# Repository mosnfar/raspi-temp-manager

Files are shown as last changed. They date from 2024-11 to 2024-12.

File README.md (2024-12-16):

# RasPi Temp Manager

A comparative tool and hardware setup for Raspberry Pi (RasPi) to manage temperature and monitor essential information.

This repository outlines a project designed to enhance the thermal management and monitoring capabilities of a Raspberry Pi 4 housed in an Argon NEO case. The project combines hardware modifications and custom software to provide effective cooling and real-time system monitoring through a small OLED display.

> [!NOTE]
> You can read the complete instructions on [The Forge blog](https://forge.mosn.me/keeping-your-raspberry-pi-cool-a-temperature-manager-tool).

<table style="width: 100%;">
  <tr>
    <th style="text-align: left;"> Final Product </th>
    <th style="text-align: left;"> Demo Video </th>
  </tr>
  <tr>
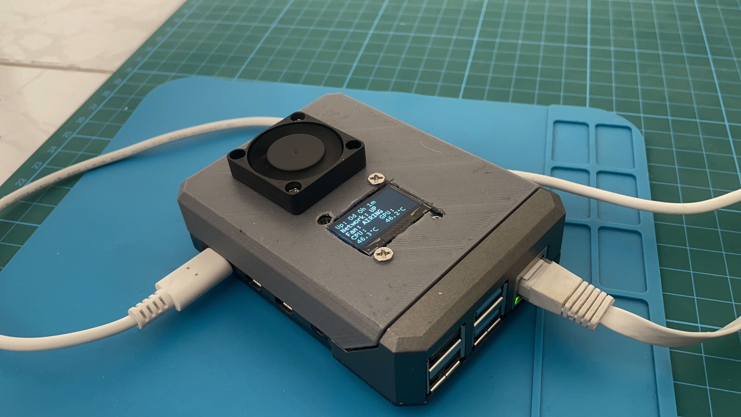
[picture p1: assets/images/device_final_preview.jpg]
Image of final product
    <td width="50%"></td>
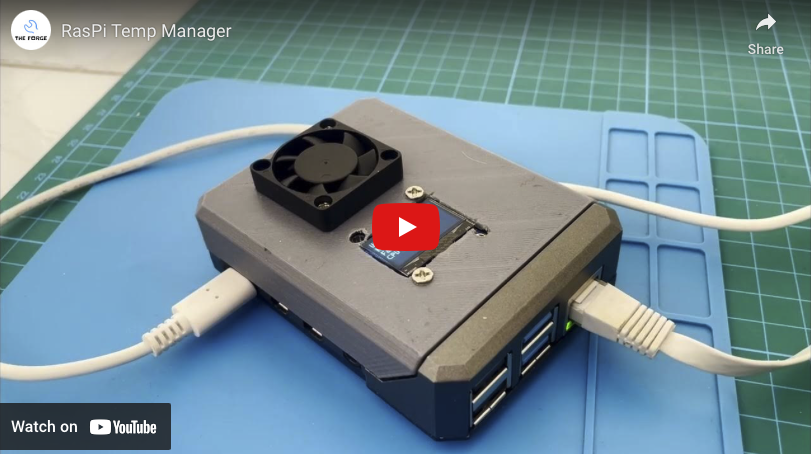
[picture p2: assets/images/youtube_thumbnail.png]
Yotube thumbnail of demo video
    <td width="50%"></td>
  </tr>
</table>

---

Table of contents:

<!-- TOC depthfrom:2 depthto:3 -->

- [:sparkles: Features](#sparkles-features)
- [:nut_and_bolt: Hardware](#nut_and_bolt-hardware)
    - [Hardware Components](#hardware-components)
    - [Schematic](#schematic)
- [:package: 3D Case](#package-3d-case)
- [:computer: Software](#computer-software)
- [:information_desk_person: More Information](#information_desk_person-more-information)
    - [Image Gallery](#image-gallery)
    - [Complete Instruction](#complete-instruction)
    - [Contribution](#contribution)

<!-- /TOC -->

---

## :sparkles: Features
- **Dynamic Cooling**: Automatically adjusts the fan speed according to system temperature thresholds.
- **Real-Time Monitoring**: Displays key metrics like:
  - CPU & GPU temperature
  - Network status
  - System overview
- **Compact Design**: Retains the Argon NEO case's form factor with minimal modifications.

## :nut_and_bolt: Hardware

### Hardware Components

1. **128×64 px OLED Display (SSD1306):** Uses I2C protocol to display system metrics, including temperature, system, and network status.
2. **Miniature 5V Fan:** Provides active cooling to maintain optimal system temperature.
3. **DRV8833 Dual Motor Driver:** Controls the 5V fan with PWM for precise speed adjustments.
4. **Raspberry Pi 4:** Serves as the mainboard.

### Schematic

Here is the schematic for connecting all components to the Raspberry Pi GPIO.

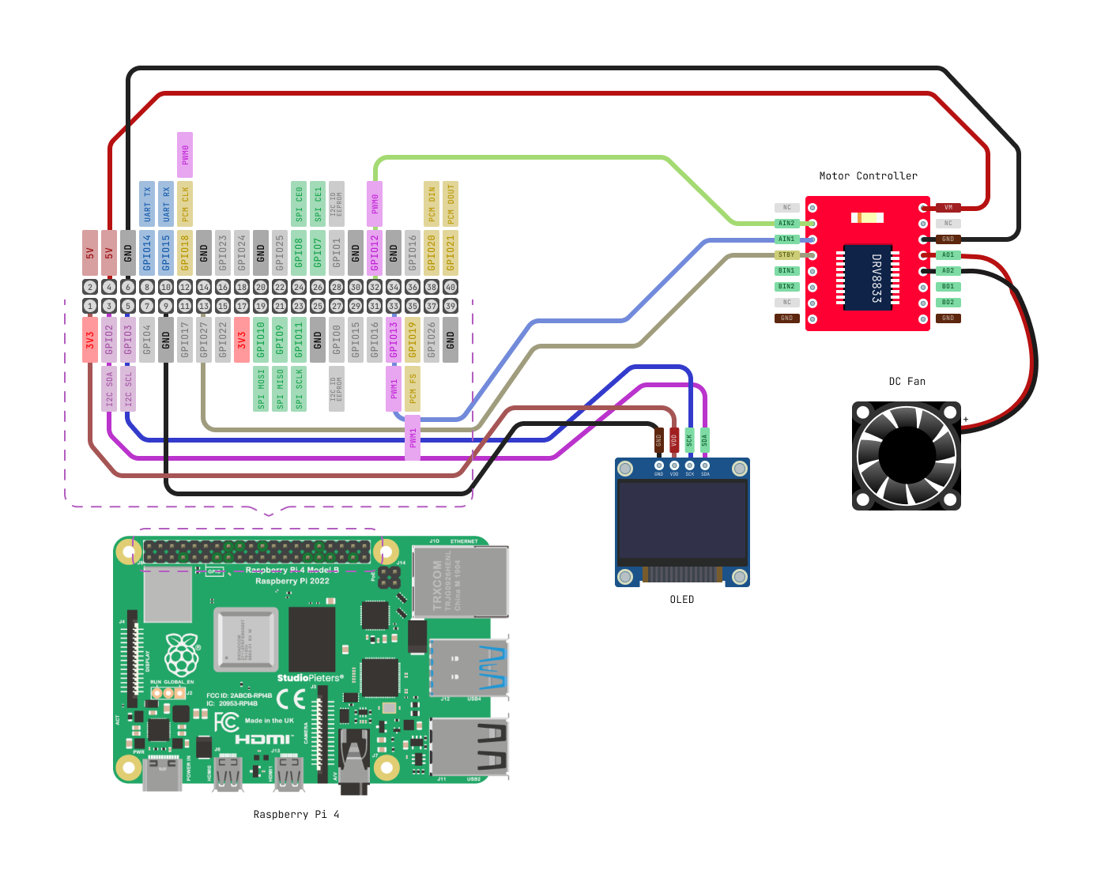
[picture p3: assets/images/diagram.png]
Schematic Diagram


#### DRV8833 Driver ←→ Rasberry Pi
| *DRV8833* | *Raspberry Pi 4 GPIO* |
| --- | --- |
| AIN1 | GPIO13 |
| AIN2 | GPIO12 |
| VM | 5V (Pin #4) |
| GND | GND (Pin #6) |
| STBY | GPIO27 |

#### 5V Fan ←→ DRV8833 Driver
| *5V Fan* | *DRV8833 Driver* |
| --- | --- |
| 5V (RED) | AIO1 |
| GND (BLACK) | AIO2 |

#### OLED (SSD1306) ←→ Raspberry Pi
| *OLED - SSD1306* | *Raspberry Pi 4 GPIO* |
| --- | --- |
| VCC | 3v3 (Pin #1) |
| SDA | GPIO2 |
| SCL | GPIO3 |
| GND | GND (Pin #9) |

## :package: 3D Case

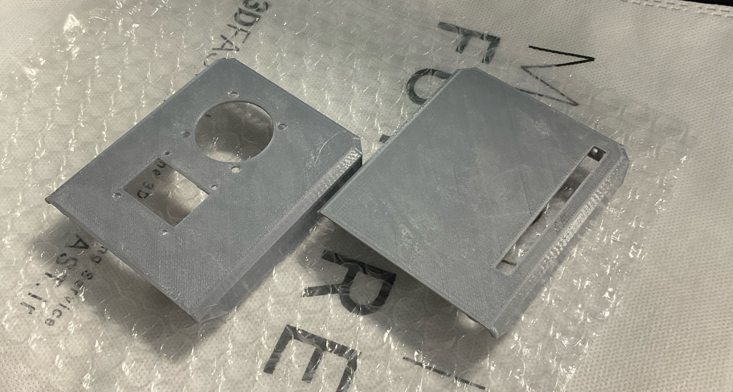
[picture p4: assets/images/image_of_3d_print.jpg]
Image of 3D printed part


I used the [Argon NEO Case](https://argon40.com/products/argon-neo-case-for-raspberry-pi-4) for my raspberry pi 4 and I modified this case to place the components. You can find the 3D design file in the [`./3d-files` directory](/3d-files/) or through this [link](https://www.printables.com/model/1085113-rascase-raspberry-pi-argon-neo-case-add-on). You can also 3D print any other case of your choice to house the components. 

## :computer: Software

#### 01. Clone Repository

Clone the repository into your raspberry pi:

```bash
git clone https://github.com/mosnfar/raspi-temp-manager
```

#### 02. Install Requirements

To run this script you need these libraries gpiozero, Pillow(PIL), and adafruit_ssd1306 that are not in raspberry pi, install requirements libraries:

```bash
pip install -r requirements.txt
```

> [!TIP]
> If you are using a newer version of Python, install the libraries globally rather than in a virtual environment.

#### 03. Copy essential files

You should copy essential files "font and boot lofo" to `/usr/local/share`, use the following command:

```bash
mkdir -p /usr/local/share/temp_manager
cp ./fonts/lucan.ttf /usr/local/share/temp_manager
cp ./images/raspberrypi_logo_inverted.bmp /usr/local/share/temp_manager
```

#### 04. Test Configs

You can test everything to make sure configs are working correctly by running `test_config.py` to check "Required libraries installation", "I2C connection", "Fan connection", and "Essential files". You can run test by this:

```bash
python test_config.py
```

#### 05. Configure Boot Script

After successful testing, configure a service to add that into system boot and the script will be running at startup. First copy `temp_manager.py` script into `/usr/local/bin`:

```bash
sudo cp ./source/temp_manager.py /usr/local/bin/
```

Now add new service for temperature manager:

```bash
sudo nano /etc/systemd/system/temp_manager.service
```

And add content below to service file:

```
[Unit]
Description=Temperature Manager
After=network.target

[Service]
ExecStart=/usr/bin/python3 /usr/local/bin/temp_manager.py
Restart=always

[Install]
WantedBy=multi-user.target
```

Finally enable and start the service to run at startup:

```bash
sudo systemctl enable temp_manager.service
sudo systemctl start temp_manager.service
```

**:smiley: Awesome, everything is set up perfectly and should work great!**

## :information_desk_person: More Information

### Image Gallery
Here are some images that highlight the project:
<table>
    <tr>
        <td align="center">
            <figure>
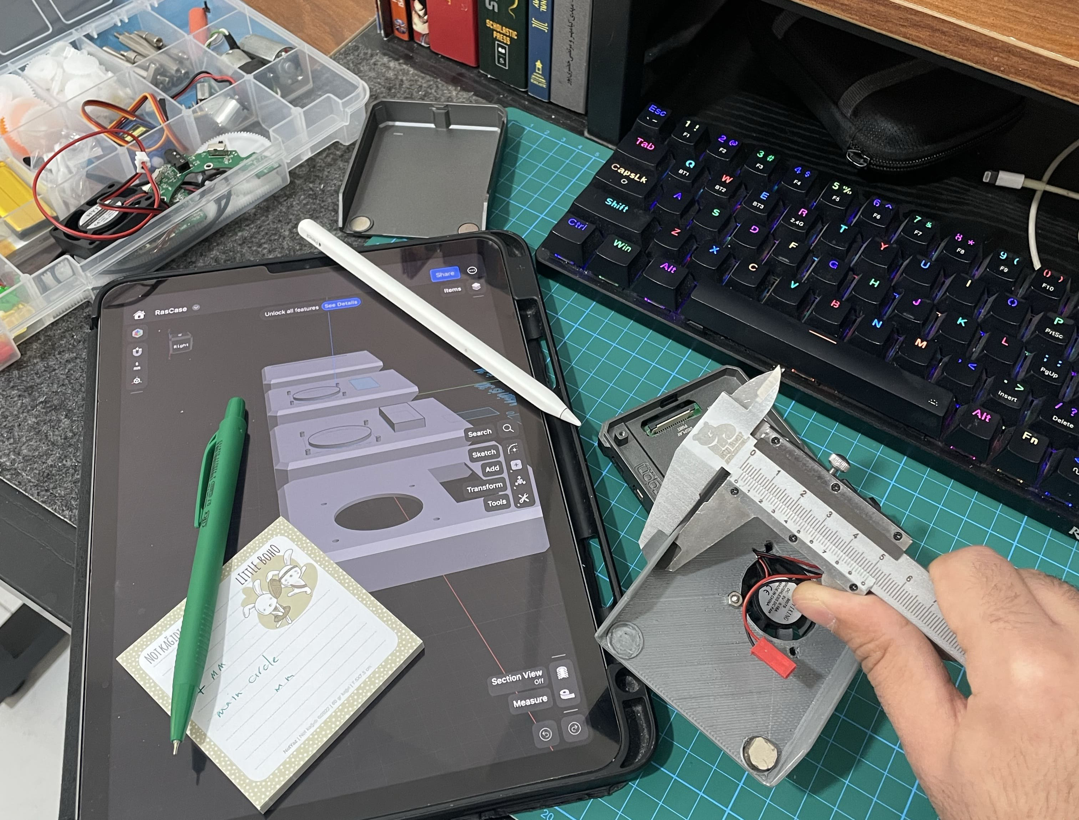
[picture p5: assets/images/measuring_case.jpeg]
                
                <figcaption>Measuring Case</figcaption>
            </figure>
        </td>
        <td align="center">
            <figure>
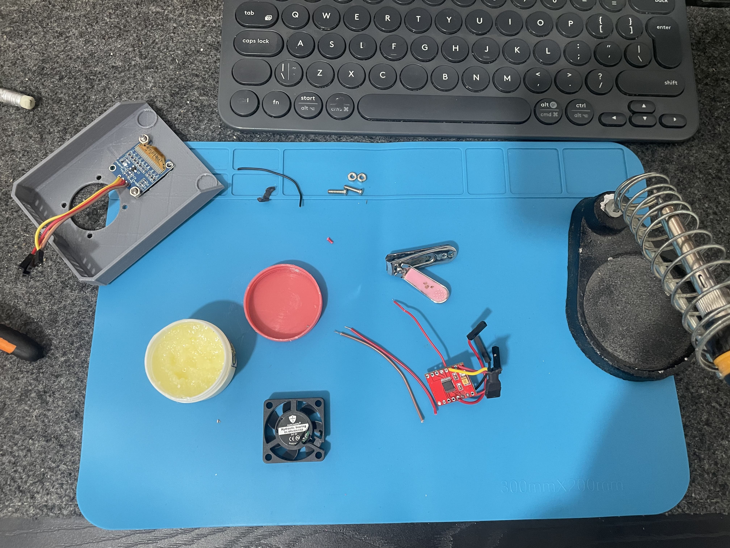
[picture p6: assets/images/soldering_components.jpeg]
                
                <figcaption>Soldering Components</figcaption>
            </figure>
        </td>
        <td align="center">
            <figure>
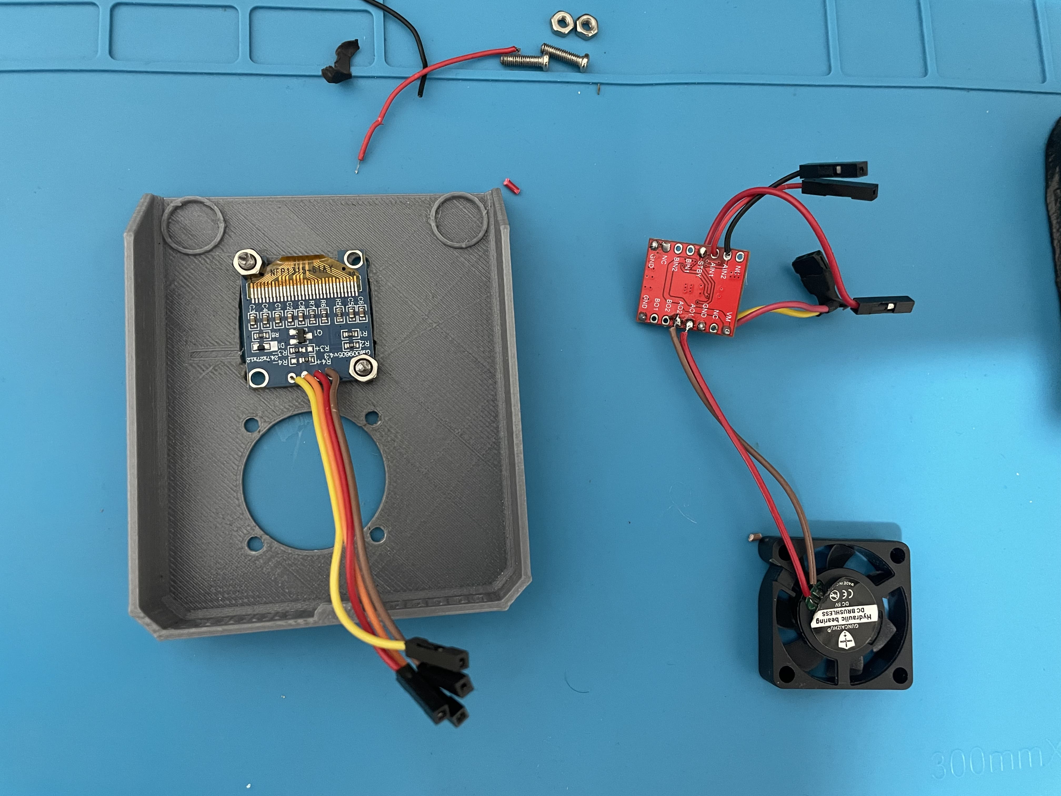
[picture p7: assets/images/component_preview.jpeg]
                
                <figcaption>Component Preview</figcaption>
            </figure>
    </tr>
    <tr>
        <td align="center">
            <figure>
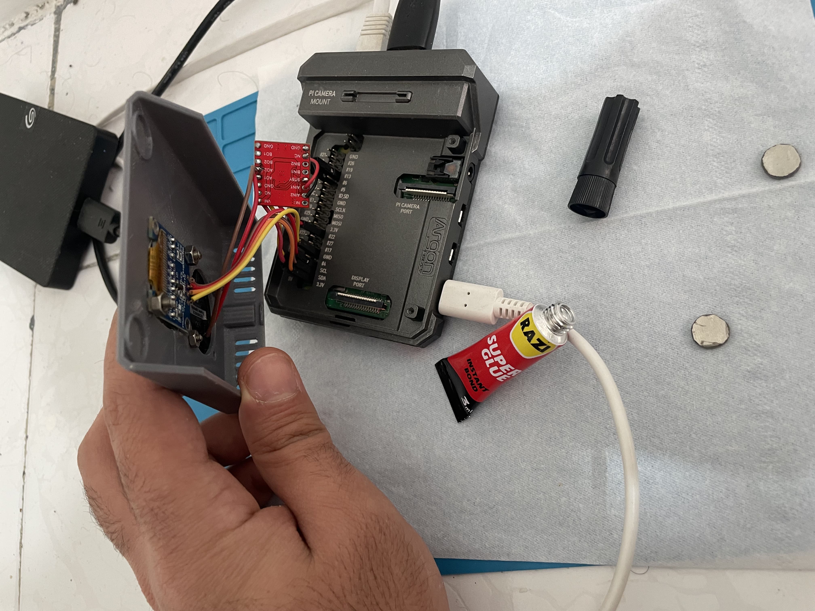
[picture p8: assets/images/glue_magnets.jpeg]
                
                <figcaption>Glue Magnets</figcaption>
            </figure>
        </td>
        <td align="center">
            <figure>
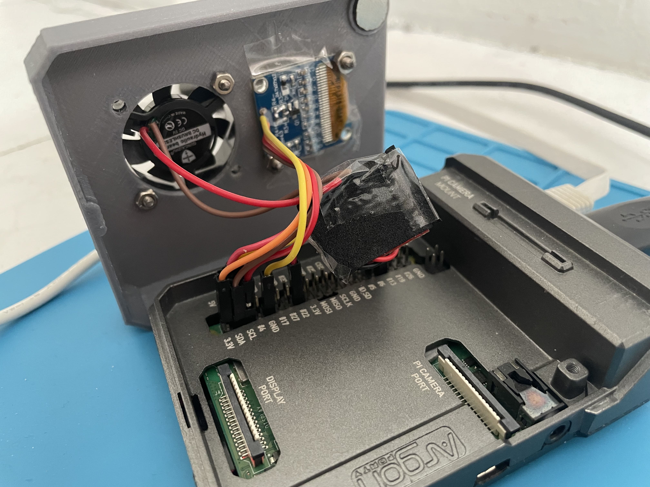
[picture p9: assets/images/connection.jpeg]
                
                <figcaption>Connection Preview</figcaption>
            </figure>
        </td>
        <td align="center">
            <figure>
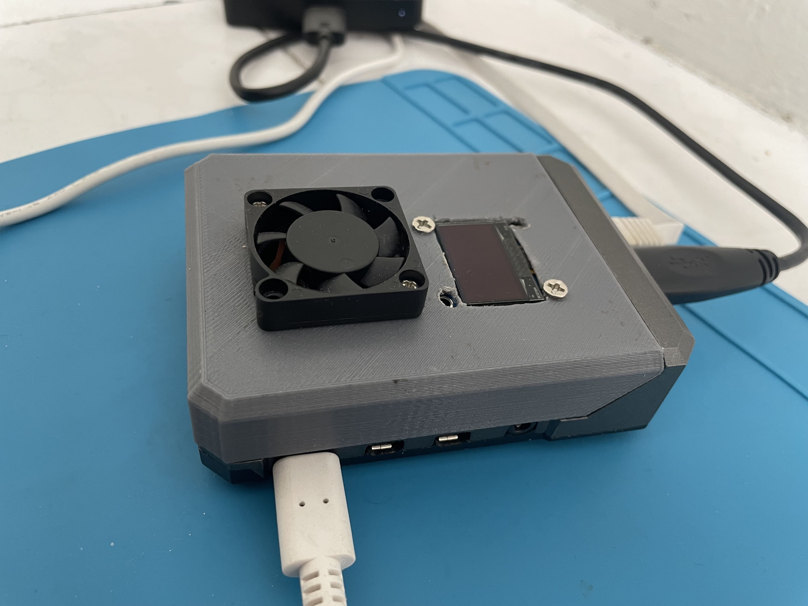
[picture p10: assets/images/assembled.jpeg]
                
                <figcaption>Assembled Product</figcaption>
            </figure>
        </td>
    </tr>
</table>

### Complete Instruction
I wrote a complete guide and instructions on my blog "The Forge" you can read it through [this link](https://forge.mosn.me/keeping-your-raspberry-pi-cool-a-temperature-manager-tool).

### Contribution
Feel free to customize and improve the project however you'd like! Your contributions are always welcome, and together we can make it even better. Don't hesitate to jump in and help out! 😊

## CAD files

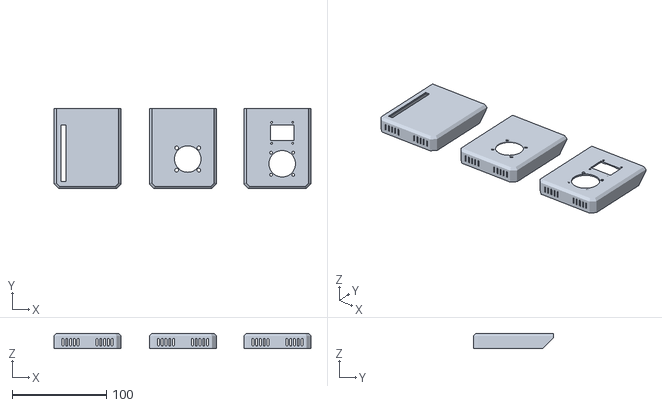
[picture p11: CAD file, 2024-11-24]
3d-files/RasCase.stl
272.0 x 85.1 x 15.6

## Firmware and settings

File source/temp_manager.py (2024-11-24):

#!/usr/bin/python

# Setting up libraries
from gpiozero import Motor
import RPi.GPIO as GPIO
import board
import busio
from adafruit_ssd1306 import SSD1306_I2C
from PIL import Image, ImageDraw, ImageFont
import time
import subprocess
import re
import os



# ------ FAN CONFIG ------

# Set fan contoroler pins
cntrl_ain1 = 12
cntrl_ain2 = 13
cntrl_standby = 22
GPIO.setmode(GPIO.BCM)
GPIO.setup(cntrl_standby, GPIO.OUT)
fan = Motor(cntrl_ain1, cntrl_ain2)



# ------ DISPLAY CONFIG ------

# Setup I2C interface
i2c = busio.I2C(board.SCL, board.SDA)

# Setup display (SSD136 module)
screen_width = 128
screen_height = 64 
display = SSD1306_I2C(screen_width, screen_height, i2c)

# Test display
display.fill(0)
display.show()

# Create blank canvas using Pillow Library
width = display.width
height = display.height
canvas = Image.new('1', (width, height), color=0)

# Setup draw command
draw = ImageDraw.Draw(canvas)

# Setup custom font (custom font = Lucida Console font, 12px Size)
font_path = "/usr/local/share/temp_manager/lucon.ttf"
if os.path.exists(font_path):
    font = ImageFont.truetype(font_path, 12)
else:
    font = ImageFont.load_default()



# ----- SETTING FUNCTIONS -----

def boot_screen(interval_loading=1):
    """ Show boot screen until system booted """

    # Logo Config
    logo_path = "/usr/local/share/temp_manager/raspberrypi_logo_inverted.bmp"
    logo = Image.open(logo_path).resize((32, 32), Image.LANCZOS).convert("1")

    for i in range(1, 4):

        canvas.paste(0, (0, 0, width, height))
        display.fill(0)
        display.show()        

        canvas.paste(logo, (48, 8))
        draw = ImageDraw.Draw(canvas)

        dots = "." * i
        x_position = 64 - (4 * i)
        draw.text((x_position, 42), dots, font=font, fill=255)

        display.image(canvas)
        display.show()

        time.sleep(interval_loading)


def is_system_booted():
    """ Check for system is booted """
    try:
        result = subprocess.run(["systemctl", "is-system-running"], capture_output=True, text=True, check=True)
        # Return True if is booted
        return result.stdout.strip() == "running"
    except subprocess.CalledProcessError:
        # Return False if is not booted
        return False

def get_temps():
    """ Get CPU & GPU temperature """
    try:
        raw_gpu_result = subprocess.run(["vcgencmd", "measure_temp"], capture_output=True, text=True, check=True)
        gpu_temp_match = re.search(r'temp=(\d+\.\d+)', raw_gpu_result.stdout)
        if gpu_temp_match:
            gpu_temp = float(gpu_temp_match.group(1))
        else:
            return None
    except subprocess.CalledProcessError:
        return None
    
    try:
        raw_cpu_result = subprocess.run(["cat", "/sys/class/thermal/thermal_zone0/temp"], capture_output=True, text=True, check=True)
        cpu_temp = float(raw_cpu_result.stdout) / 1000
    except subprocess.CalledProcessError:
        return None
    
    return {
        # Return temperatures as float numbers
        "cpu": cpu_temp,
        "gpu": gpu_temp
    }

def get_uptime():
    """ Get system uptime """
    try:
        result = subprocess.run(["uptime", "-p"], capture_output=True, text=True, check=True)
        uptime_str = result.stdout.strip()
    except subprocess.CalledProcessError:
        return None
    
    days = hours = minutes = 0

    day_match = re.search(r'(\d+)\s+days?', uptime_str)
    hour_match = re.search(r'(\d+)\s+hours?', uptime_str)
    minute_match = re.search(r'(\d+)\s+minutes?', uptime_str)

    if day_match:
        days = int(day_match.group(1))
    if hour_match:
        hours = int(hour_match.group(1))
    if minute_match:
        minutes = int(minute_match.group(1))

    return {
        # Return uptime days, hours, minutes as array
        "days": days,
        "hours": hours,
        "minutes": minutes
    }



def check_network():
    """ Get network status by attempt to ping Google CDN (8.8.8.8)"""
    try:
        response = subprocess.run(["ping", "-c", "1", "-W", "2", "8.8.8.8" ], stdout=subprocess.DEVNULL, stderr=subprocess.DEVNULL)
        # Return UP if internet is connected and DOWN otherwise
        if response.returncode == 0:
            return "UP"
        else:
            return "DOWN"
        
    except subprocess.SubprocessError:
        return "DOWN"


def temp_checker():
    """ Check maximum temperature and return fan speed mode """
    
    local_temps = get_temps()

    FAN_SPEEDS = {
        "QUIET": 0.0,
        "ECHO": 0.3,
        "AIRING": 0.6,
        "TURBO": 1.0,
        "OVERHEAT": 1.0
    }
    
    MAX_TEMP = max(local_temps["cpu"], local_temps["gpu"])

    if MAX_TEMP < 40:
        mode = "QUIET"
        active = False
    elif MAX_TEMP < 45:
        mode = "ECHO"
        active = True
    elif MAX_TEMP < 60:
        mode = "AIRING"
        active = True
    elif MAX_TEMP < 80:
        mode = "TURBO"
        active = True
    else:
        mode = "OVERHEAT"
        active = True

    fan_speed = FAN_SPEEDS[mode]

    return {
        # Return fan mode and speed based on max temp
        "mode": mode,
        "fan_speed": fan_speed,
        "max_temp": MAX_TEMP,
        "fan_active": active
    }



def main():
    """ Loop for main script function """

    while not is_system_booted():
        # Load boot screen until system is booted
        boot_screen()
        time.sleep(1)

    while True:

        # Store function result data
        uptime_data = get_uptime()
        fan_data = temp_checker()
        network_data = check_network()
        temp_data = get_temps()

        # Clear screen
        canvas.paste(0, (0, 0, width, height))
        display.fill(0)
        display.show()

        # Set data in screen canvas
        draw.text((0, 0), "Up: " + str(uptime_data["days"]) + "d " + str(uptime_data["hours"]) + "h " + str(uptime_data["minutes"]) + "m", font=font, fill=255)
        draw.text((0, 12), "Network: " + network_data, font=font, fill=255)
        draw.text((0, 24), "Fan: " + fan_data['mode'], font=font, fill=255)
        draw.text((0, 36), "CPU: ", font=font, fill=255)
        draw.text((64, 36), "GPU: ", font=font, fill=255)
        draw.text((0, 48), str(round(temp_data["cpu"],1)) + "°C", font=font, fill=255)
        draw.text((64, 48), str(round(temp_data["gpu"],1)) + "°C", font=font, fill=255)

        # Show canvas on screen
        display.image(canvas)
        display.show()

        # Set fan contoroler STNDBY pin
        GPIO.output(cntrl_standby, fan_data["fan_active"])
        # Run fan based on fan setup
        fan.forward(fan_data['fan_speed'])

        time.sleep(10)

# main() function calling
if __name__ == "__main__":
    main()

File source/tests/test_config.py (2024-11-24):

import sys
import os

# ANSI color codes
COLOR_RESET = "\033[0m"
COLOR_YELLOW = "\033[33m"
COLOR_RED = "\033[31m"
COLOR_GREEN = "\033[32m"

# Function to check if a library is installed
def check_library(library_name):
    """Check if a library is installed."""
    try:
        __import__(library_name)
        print(f"Library '{library_name}' is installed.")
        return True
    except ImportError:
        print(f"Library '{library_name}' is {COLOR_YELLOW}NOT{COLOR_RESET} installed.")
        return False

# List of required libraries
libraries = ["gpiozero", "RPi.GPIO", "board", "busio", "adafruit_ssd1306", "PIL"]
missing_libraries = []

print("\nChecking libraries...\n")
for lib in libraries:
    if not check_library(lib):
        missing_libraries.append(lib)

# Exit if any libraries are missing
if missing_libraries:
    print(f"\n{COLOR_RED}The following libraries are missing and need to be installed:{COLOR_RESET}")
    for lib in missing_libraries:
        print(f" - {COLOR_RED}{lib}{COLOR_RESET}")
    sys.exit("\nExiting script due to missing libraries.\n")
else:
    print(f"\n{COLOR_GREEN}All required libraries are installed.{COLOR_RESET}\n\nProceeding with the script...\n")

# Import verified libraries
import board
import busio
from adafruit_ssd1306 import SSD1306_I2C
from gpiozero import Motor
import RPi.GPIO as GPIO
import time

print("\nLibraries imported successfully.")

# Set GPIO mode
GPIO.setmode(GPIO.BCM)
 
# Function to test the i2c display
def test_i2c(screen_width=128, screen_height=64):
    """Test i2c connection and display functionality."""
    print("\nTesting display i2c connection...")

    try:
        i2c = busio.I2C(board.SCL, board.SDA)
        disp = SSD1306_I2C(screen_width, screen_height, i2c)

        disp.fill(1)
        disp.show()
        print("Screen turned on. Waiting for 2 seconds...")
        time.sleep(2)

        disp.fill(0)
        disp.show()
        print("Screen turned off")

        print(f"{COLOR_GREEN}Screen is configured correctly{COLOR_RESET}")
    except Exception as e:
        print(f"{COLOR_RED}Screen isn't configured correctly.{COLOR_RESET}\nError: {e}")

# Function to test fan functionality
def test_fan(cntrl_ain1=12, cntrl_ain2=13, cntrl_standby=22):
    """Test fan connection and control functionality."""
    print("\nTesting fan connection...")

    try:
        GPIO.setup(cntrl_standby, GPIO.OUT)
        
        # Use `with` statement for automatic cleanup with gpiozero Motor
        with Motor(cntrl_ain1, cntrl_ain2) as fan:
            GPIO.output(cntrl_standby, True)
            
            print("Running fan at half speed for 5 seconds...")
            fan.forward(0.5)
            time.sleep(5)

            print("Running fan at full speed for 5 seconds...")
            fan.forward(1)
            time.sleep(5)

            print(f"{COLOR_GREEN}Fan is configured correctly{COLOR_RESET}")

    except Exception as e:
        print(f"{COLOR_RED}Fan isn't configured correctly.{COLOR_RESET}\nError: {e}")


def test_files():
    directory = "/usr/local/share/temp_manager/"
    files = {"Font": "lucon.ttf", "Boot Logo": "raspberrypi_logo_inverted.bmp"}

    if not os.path.isdir(directory):
        print(f"\n{COLOR_RED}The directory {directory} does not exist.{COLOR_RESET}")
        print(f"Hint: Please create {directory} and place {files['Font']} and {files['Boot Logo']} into it.")
        print(f"Commands:")
        print(f"mkdir -p {directory}")
        print(f"cp ../fonts/{files['Font']} {directory}")
        print(f"cp ../images/{files['Boot Logo']} {directory}{COLOR_RESET}")
        return

    for file_name in files:
        file_path = os.path.join(directory, files[file_name])
        if os.path.isfile(file_path):
            print(f"\n{COLOR_GREEN}{file_name} is places correctly in {directory}{COLOR_RESET}")
        else:
            print(f"\n{COLOR_RED}{file_name} is missing.{COLOR_RESET}")
            source_hint = "fonts" if file_name == "Font" else "images"
            print(f"Hint: Please copy {files[file_name]} from 'repo'/source/{source_hint}/ to {directory}")
            print(f"Command: cp ../{source_hint}/{files[file_name]} {directory}{COLOR_RESET}")


# Main function
def main():
    """Main function to test fan and screen."""
    print("\nStarting tests for fan and screen...")
    test_i2c()
    test_fan()
    print("\nAll hardware tests completed.")
    print("\nChecking for essntial files...")
    test_files()
    print("\nAll tests are done")

# main() function calling
if __name__ == "__main__":
    main()
